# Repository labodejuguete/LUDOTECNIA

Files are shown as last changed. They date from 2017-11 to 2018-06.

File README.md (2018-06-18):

# LUDOTECNIA
LUDOTECNIA es un circuito sonoro basado en ATTINY85 y la vez el lanzamiento físico del disco del mismo nombre (j.crowe)
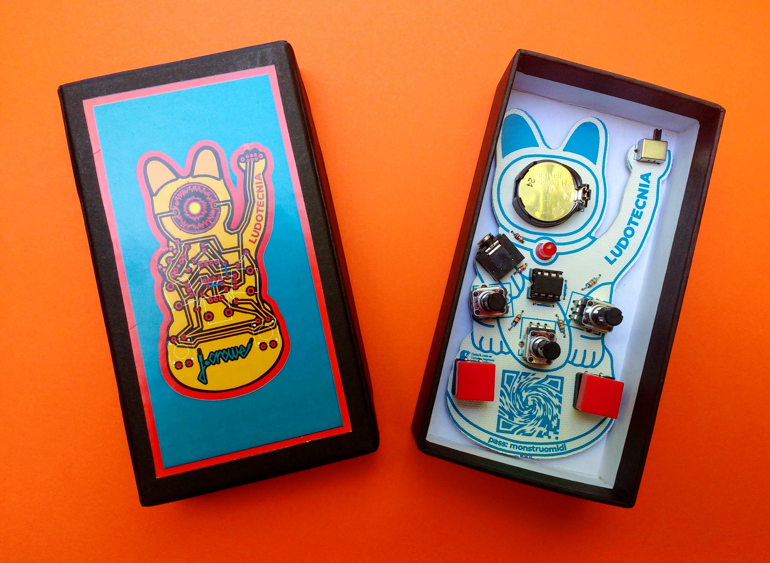
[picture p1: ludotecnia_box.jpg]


VIDEO: https://youtu.be/s6Rd__J4UZs

LUDOTECNIA hace uso del código de Kastle VCO desarrollado por Vaclav Pelousek
open source license: CC BY SA
https://github.com/bastl-instruments/kastle/tree/master/kastleSynthe_VCO
http://www.bastl-instruments.com

LUDOTECNIA fue diseñado con Fritzing e Inkscape
http://fritzing.org/home/
https://inkscape.org

PODÉS ESCUCHAR EL DISCO ONLINE EN EL SIGUIENTE ENLACE:
http://www.jcrowe.xyz/ludotecnia/

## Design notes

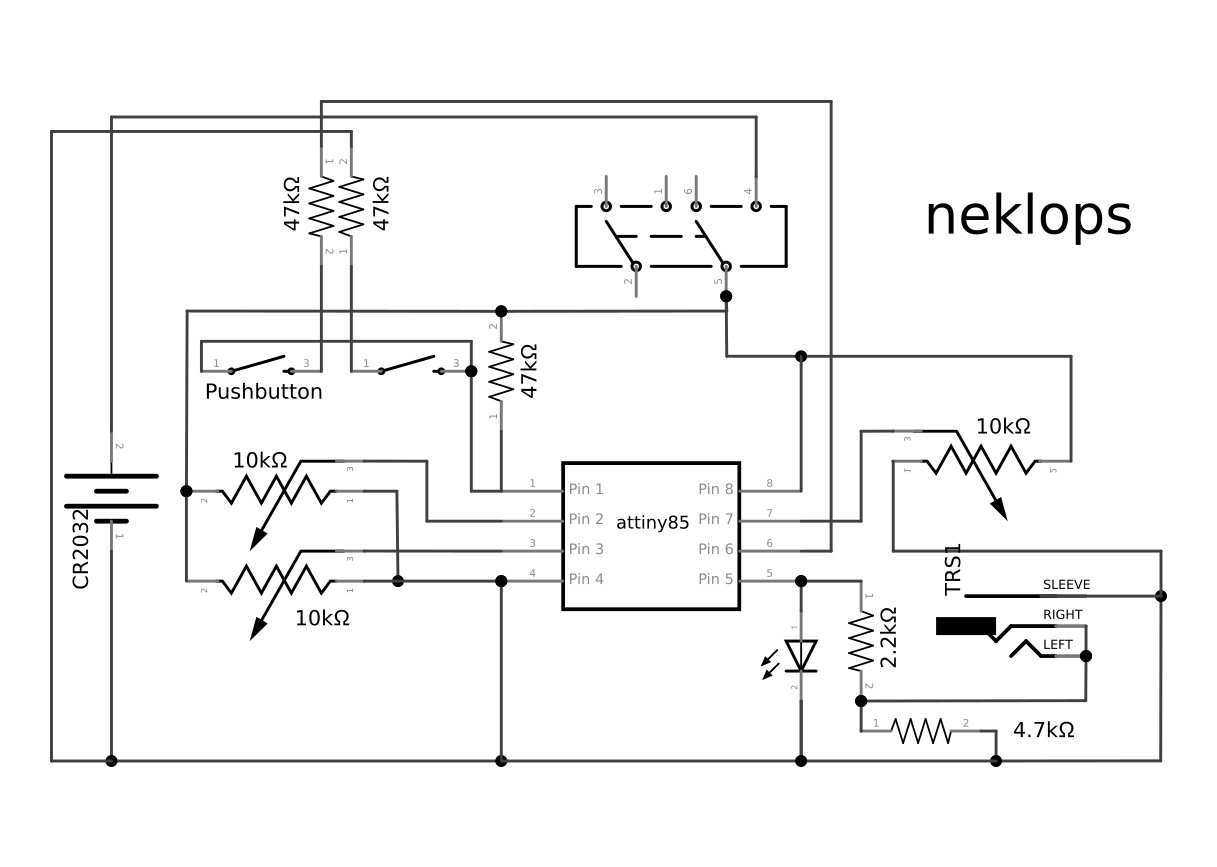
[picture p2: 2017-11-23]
hardware/neklops_schematic.jpg

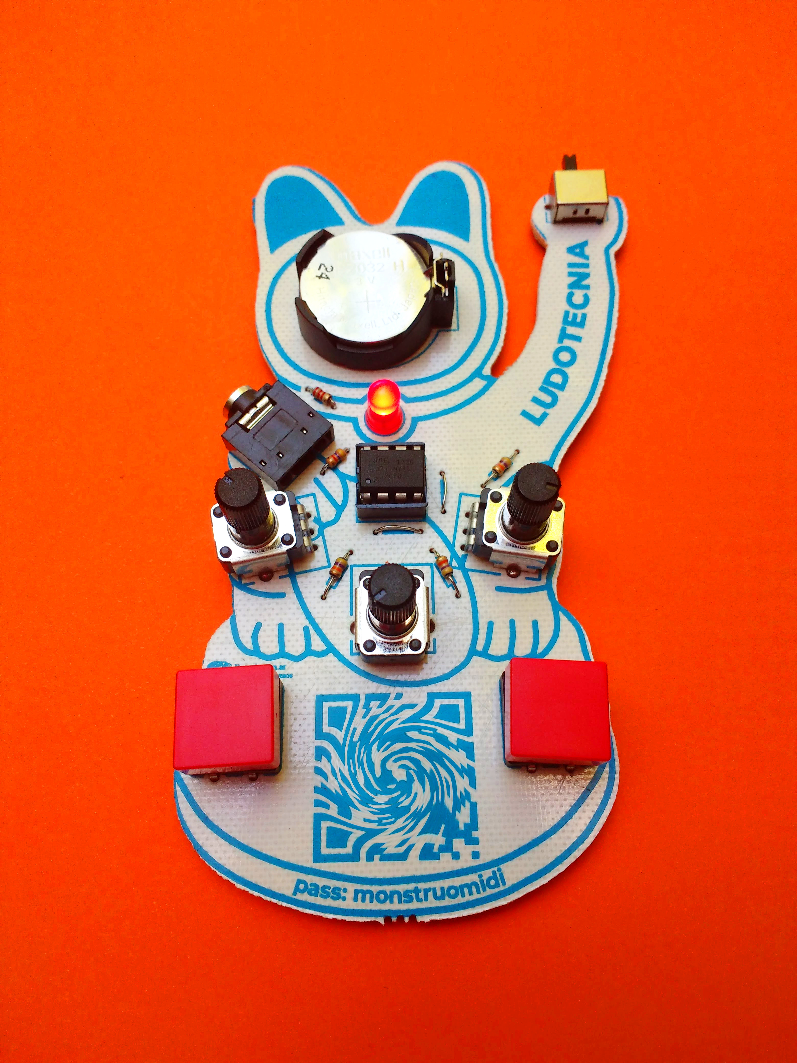
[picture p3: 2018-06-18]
ludotecnia_front.jpg

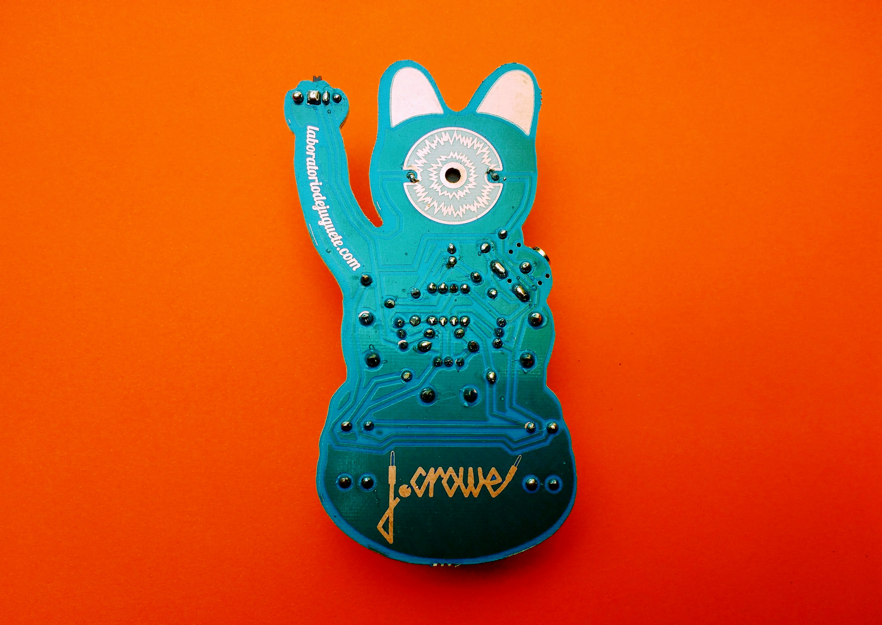
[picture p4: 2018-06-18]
ludotecnia_back.jpg

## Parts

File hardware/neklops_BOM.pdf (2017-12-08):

# Bill of Materials: neklops.fzz

## Assembly List

Label | Part Type | Properties
CR2032 | Battery Holders | package battcom_20mm_pth; variant 20pth
LED1 | Red (633nm) LED | leg yes; color Red (633nm); package 5 mm [THT]
ON/OFF | SWITCH-DPDT | package eg2211; variant eg2211

Pushbutton SWITCH-MOMENTARY-2 package tactile-pth-12mm; variant 12mm

R1 | Rotary Potentiometer (Small) | track Linear; type Rotary Shaft Potentiometer; size Rotary - 9mm; package THT; maximum resistance 10kΩ
R2 | Rotary Potentiometer (Small) | track Linear; type Rotary Shaft Potentiometer; size Rotary - 9mm; package THT; maximum resistance 10kΩ
R3 | Rotary Potentiometer (Small) | track Linear; type Rotary Shaft Potentiometer; size Rotary - 9mm; package THT; maximum resistance 10kΩ
R4 | 47kΩ Resistor | bands 4; pin spacing 400 mil; package THT; resistance 47kΩ; tolerance ±5%
R5 | 47kΩ Resistor | bands 4; pin spacing 400 mil; package THT; resistance 47kΩ; tolerance ±5%
R6 | 47kΩ Resistor | bands 4; pin spacing 400 mil; package THT; resistance 47kΩ; tolerance ±5%
R7 | 4.7kΩ Resistor | bands 4; pin spacing 400 mil; package THT; resistance 4.7kΩ; tolerance ±5%
R8 | 4.7kΩ Resistor | bands 4; pin spacing 400 mil; package THT; resistance 4.7kΩ; tolerance ±5%

Pushbutton SWITCH-MOMENTARY-2 package tactile-pth-12mm; variant 12mm

TRS1 | Audio Jack (TRS) 3.5mm | size 3.5 mm; package 4Ucon 08780 [THT]; channels Stereo (TRS)
U1 | attiny85 | version Attiny85-20PU; type Atmel AVR; package dip; variant dip08 THT

## Shopping List

Amount Part Type | Properties
1 | Battery Holders | package battcom_20mm_pth; variant 20pth
1 | Red (633nm) LED | leg yes; color Red (633nm); package 5 mm [THT]
1 | SWITCH-DPDT | package eg2211; variant eg2211
2 | SWITCH-MOMENTARY-2 package tactile-pth-12mm; variant 12mm
3 | Rotary Potentiometer (Small) | track Linear; type Rotary Shaft Potentiometer; size Rotary - 9mm; package THT; maximum resistance 10kΩ
3 | 47kΩ Resistor | bands 4; pin spacing 400 mil; package THT; resistance 47kΩ; tolerance ±5%
2 | 4.7kΩ Resistor | bands 4; pin spacing 400 mil; package THT; resistance 4.7kΩ; tolerance ±5%
1 | Audio Jack (TRS) 3.5mm | size 3.5 mm; package 4Ucon 08780 [THT]; channels Stereo (TRS)
1 | attiny85 | version Attiny85-20PU; type Atmel AVR; package dip; variant dip08 THT

Exported with Fritzing 0.9.3- http://fritzing.org

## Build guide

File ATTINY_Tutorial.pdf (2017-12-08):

LABORATORIO | DE | JUGUETE
Tutorial: | cómo | programar | el | attiny85 | en | la | IDE | de | Arduino

Antes de empezar refrescamos un poco la data acerca de la familia ATTINY25/45/85: Son los microcontroladores ideales para hacer tareas sencillas que no demanden muchos pines ni memoria.

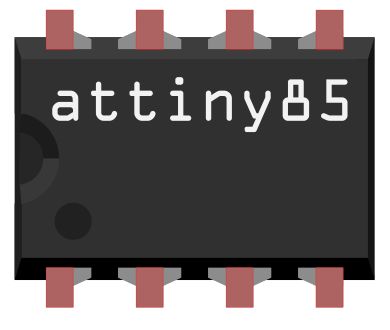
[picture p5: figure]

Ésta familia de microcontroladores tiene apenas 8 patitas y su memoria flash (el lugar donde se alberga nuestro código) es de 8, 4 o 2 kilobytes (de acuerdo al número en su nombre). Pero para muchas de las cosas que solemos hacer con arduino suele ser suficiente!

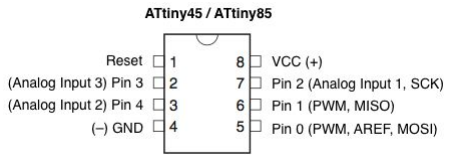
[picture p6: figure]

Como verás en el esquema de arriba, tiene 5 entradas/ salidas digitales de las cuales tres, pueden ser usadas como entradas analógicas. A que varios de tus proyectos en Arduino no usan más que ésto, no?
Y cómo hacemos para programar estas cucarachitas usando la IDE (http://www.arduino.cc/en/pmwiki.php?n=Main/Software) de Arduino?
Éstos son los pasos a seguir:
- Si no has instalado la IDE de Arduino o tienes una versión anterior a la 1.7, ingresa al siguiente link, descarga e instala la última versión disponible de acuerdo a tu sistema operativo y arquitectura:
WINDOWS (https://www.arduino.cc/download_handler.php?f=/arduino-1.8.5-windows.exe)
MAC (https://www.arduino.cc/download_handler.php?f=/arduino-1.8.5-macosx.zip)
LINUX | (32bit) (https://www.arduino.cc/download_handler.php?f=/arduino-1.8.5-linux32.tar.xz)
LINUX | (64bit) (https://www.arduino.cc/download_handler.php?f=/arduino-1.8.5-linux64.tar.xz)
- A continación te presentamos el Core (núcleo) que vamos a usar: ATTinyCore (de
| Spence Konde). (https://github.com/SpenceKonde/ATTinyCore) Puedes echar un vistazo al repositorio o por ahora simplemente copiar
| la dirección de aquí debajo:

### http://drazzy.com/package_drazzy.com_index.json

- Abrí la IDE de Arduino y dirigite a Archivo/Preferencias
- Allí encontrarás un cuadro con el nombre "Gestor de URLs adicionales de tarjetas ". Pegá en el cuadro la dirección que copiaste antes y hacé clic en OK

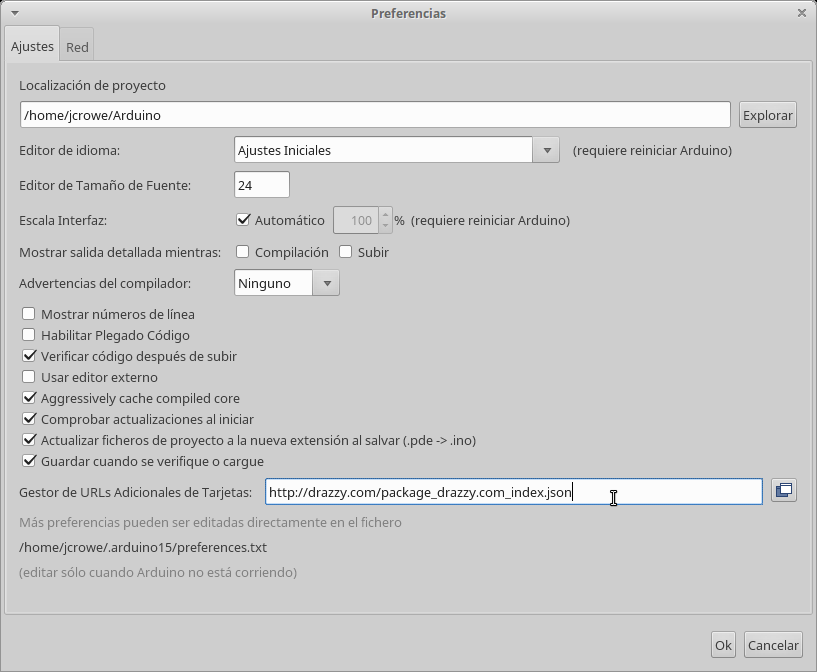
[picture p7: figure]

- Ahora dirigite a Herramientas/Placa/Gestor de tarjetas. Dale un momento al gestor para que se actualize e incorpore la ruta que pegaste en el paso anterior. Luego escribí "tiny" en el buscador. Aparecerá "ATTinyCore by Spence Konde"; hacé click en "instalar".

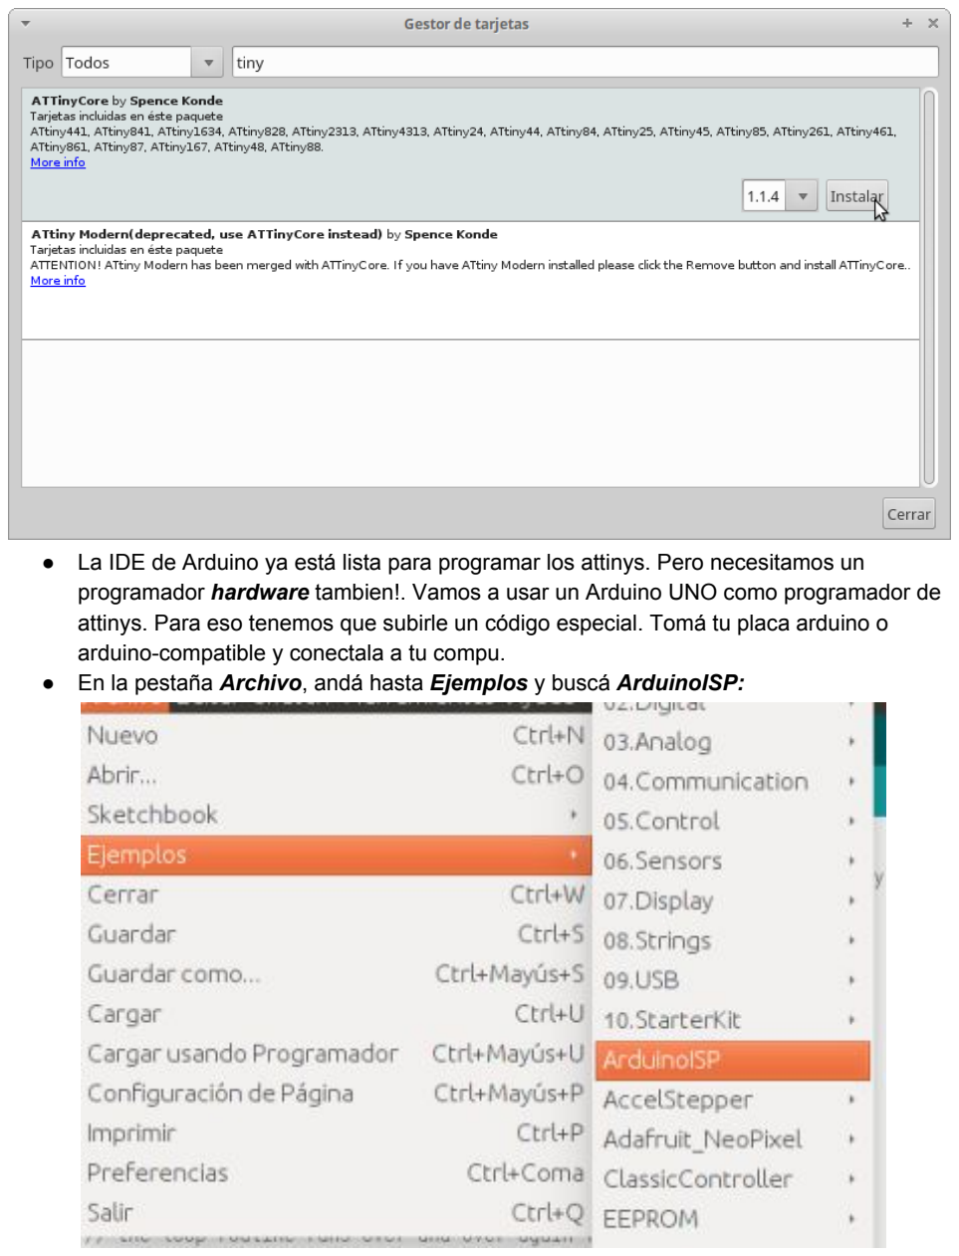
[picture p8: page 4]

- La IDE de Arduino ya está lista para programar los attinys. Pero necesitamos un programador hardware tambien!. Vamos a usar un Arduino UNO como programador de attinys. Para eso tenemos que subirle un código especial. Tomá tu placa arduino o arduino-compatible y conectala a tu compu.
- En la pestaña Archivo, andá hasta Ejemplos y buscá ArduinoISP:

- Subí el sketch a tu placa Arduino Uno (damos por sentado que ya sabés cómo elegir la placa y el puerto de comunicación):

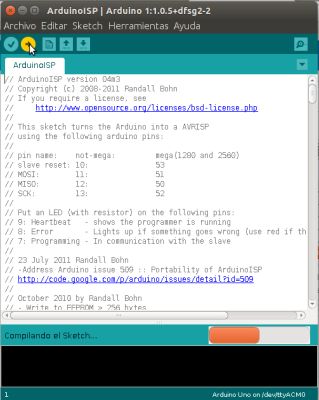
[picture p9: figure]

- Acabás de convertir a tu arduino en un programador de microcontroladores. Para usarlo como tal, sólo tenés que dar un paso más. Andá a la pestaña Herramientas, luego a Programador y elegí Arduino as ISP:

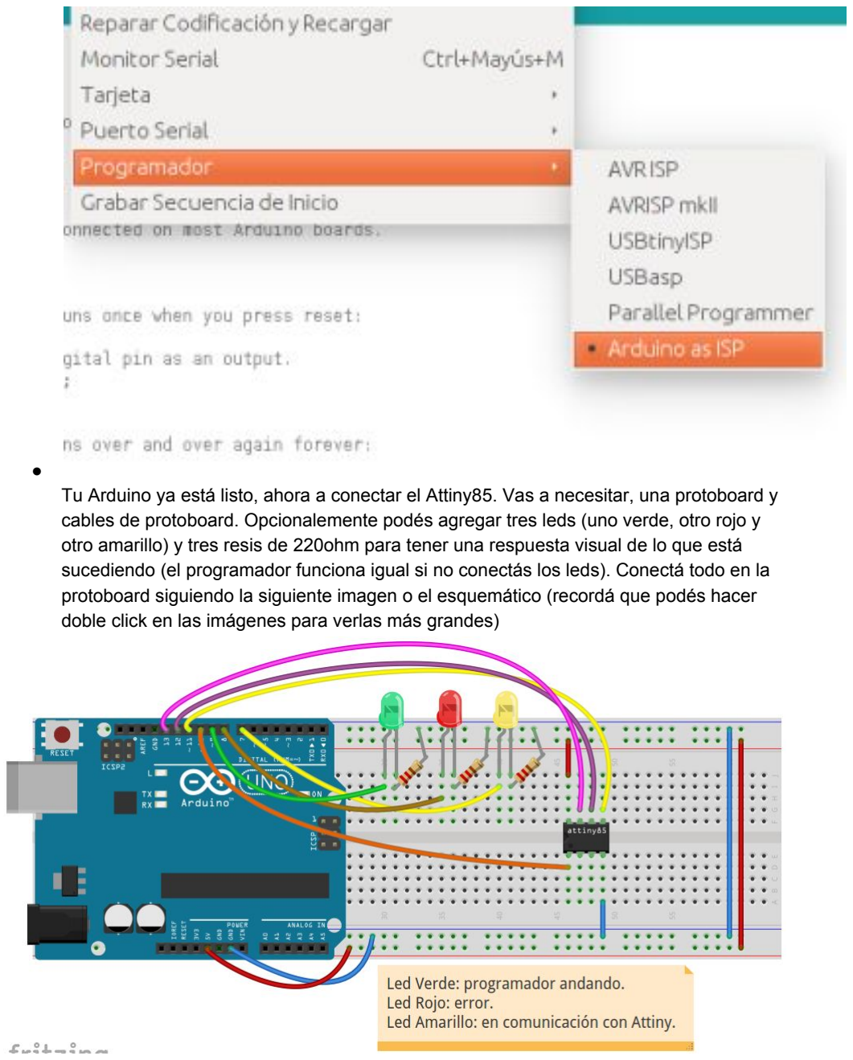
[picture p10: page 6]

●
Tu Arduino ya está listo, ahora a conectar el Attiny85. Vas a necesitar, una protoboard y cables de protoboard. Opcionalemente podés agregar tres leds (uno verde, otro rojo y otro amarillo) y tres resis de 220ohm para tener una respuesta visual de lo que está sucediendo (el programador funciona igual si no conectás los leds). Conectá todo en la protoboard siguiendo la siguiente imagen o el esquemático (recordá que podés hacer doble click en las imágenes para verlas más grandes)

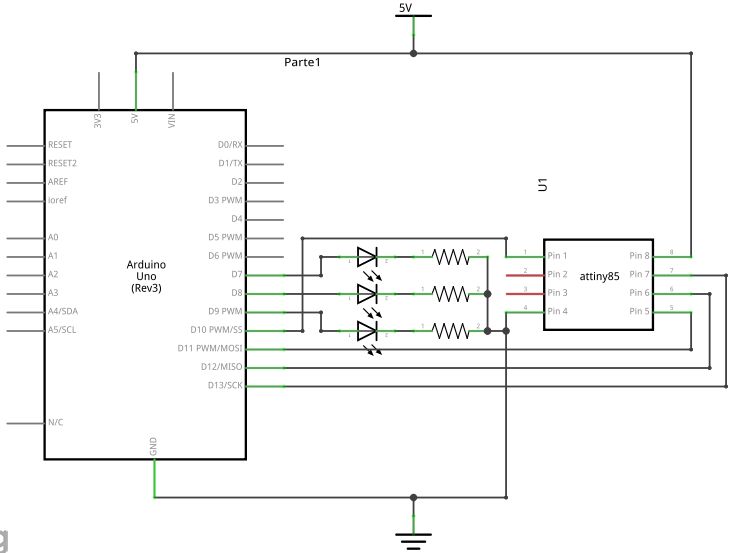
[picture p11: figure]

- Vamos a elegir el chip que estamos usando (en éste caso el attiny85). Andá a Herramientas/Placa y deslizate hacia abajo hasta que aparezca la opción attiny25/45/85. Seleccionala:

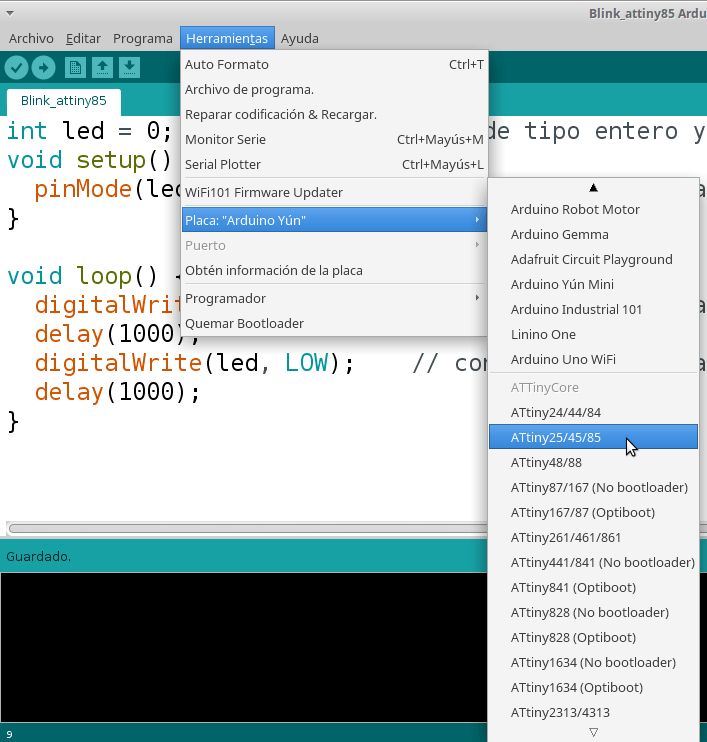
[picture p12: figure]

Si tu chip es efectivamente un Attiny85, no tenés que cambiar ninguna opción. Si en lugar de tener un attiny85, tenés un 25 o 45, vas a tener que cambiar el tipo de chip ingresando nuevamente a Herramientas.

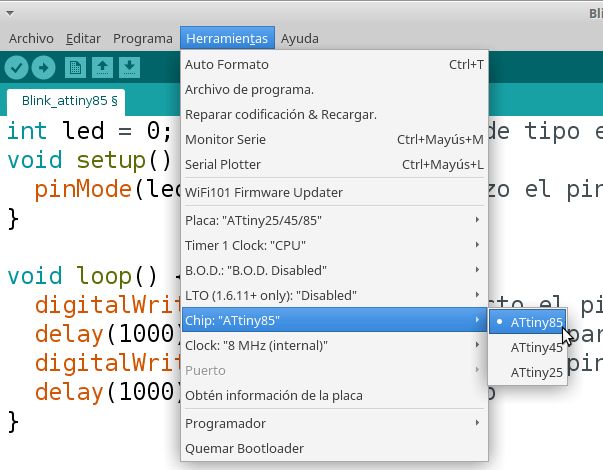
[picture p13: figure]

La siguiente acción se realiza sólo una vez, al principio, con cada chip que compres. Es la carga del bootloader o sistema de arranque. Una vez quemado el bootloader, tu chip está listo para ser programado una y otra vez. Andá a Herramientas y presioná "Cargar bootloader (recordá tener seleccionado "Arduino as ISP" como programador).

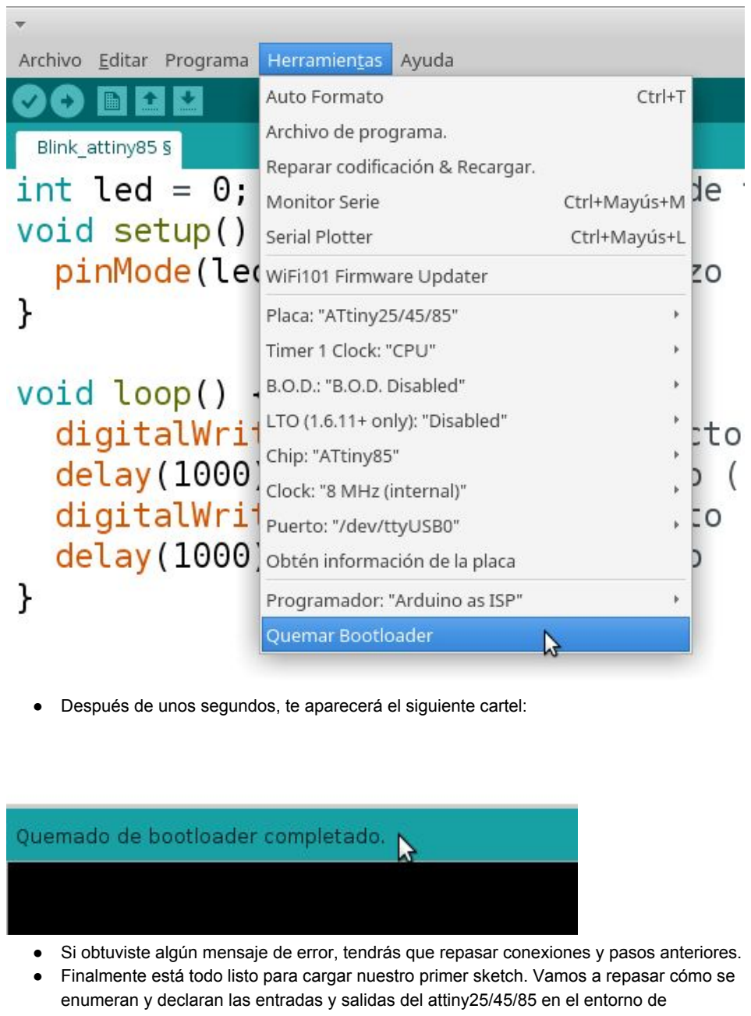
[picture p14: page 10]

- Después de unos segundos, te aparecerá el siguiente cartel:
- Si obtuviste algún mensaje de error, tendrás que repasar conexiones y pasos anteriores.
- Finalmente está todo listo para cargar nuestro primer sketch. Vamos a repasar cómo se enumeran y declaran las entradas y salidas del attiny25/45/85 en el entorno de programación de Arduino. En rojo verás el número con el que se declaran las entradas analógicas y en celeste las entradas/salidas digitales. En verde están indicadas las salidas digitales que permiten usar la función "analogWrite" (PWM).

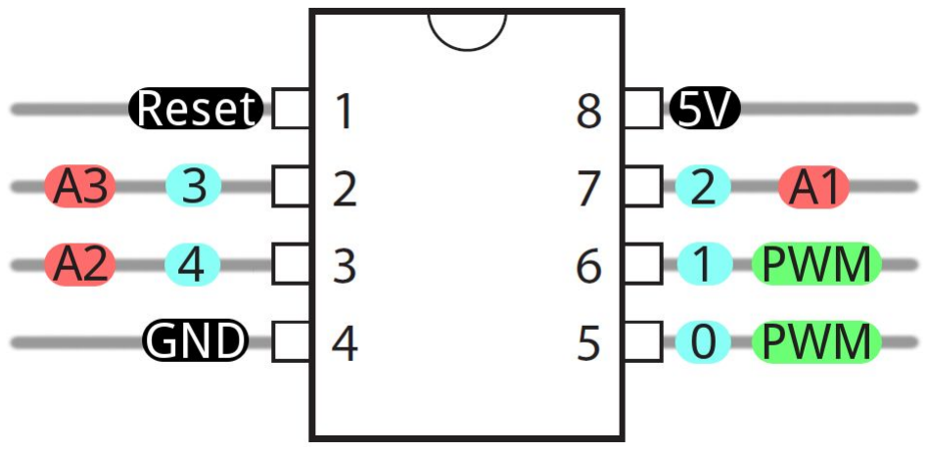
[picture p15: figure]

- Para testear la comunicación entre arduino y attiny (en este caso un attiny85) , vamos a usar el clásico ejemplo Blink que hace parpadear un led a un ritmo constante de un segundo. Para ello usaremos un led (y una resistencia de 220 Ohms) conectado a la pata 5 (Digital 0) Acá tenés un LINK (https://create.arduino.cc/editor/toylab/379f984c-477a-4e85-be1e-d4f69fa686af/preview) al archivo ya modificado para su uso en este tutorial. Copiá y pegá en un sketch vacío. Alternativamente podés abrir el ejemplo blink ubicado en Archivo/Ejemplo/Basics/Blink y reemplazar LED_BUILTIN por el valor 0 en todos los casos. Si copiaste y pegaste el texto del link, tu sketch se verá así:

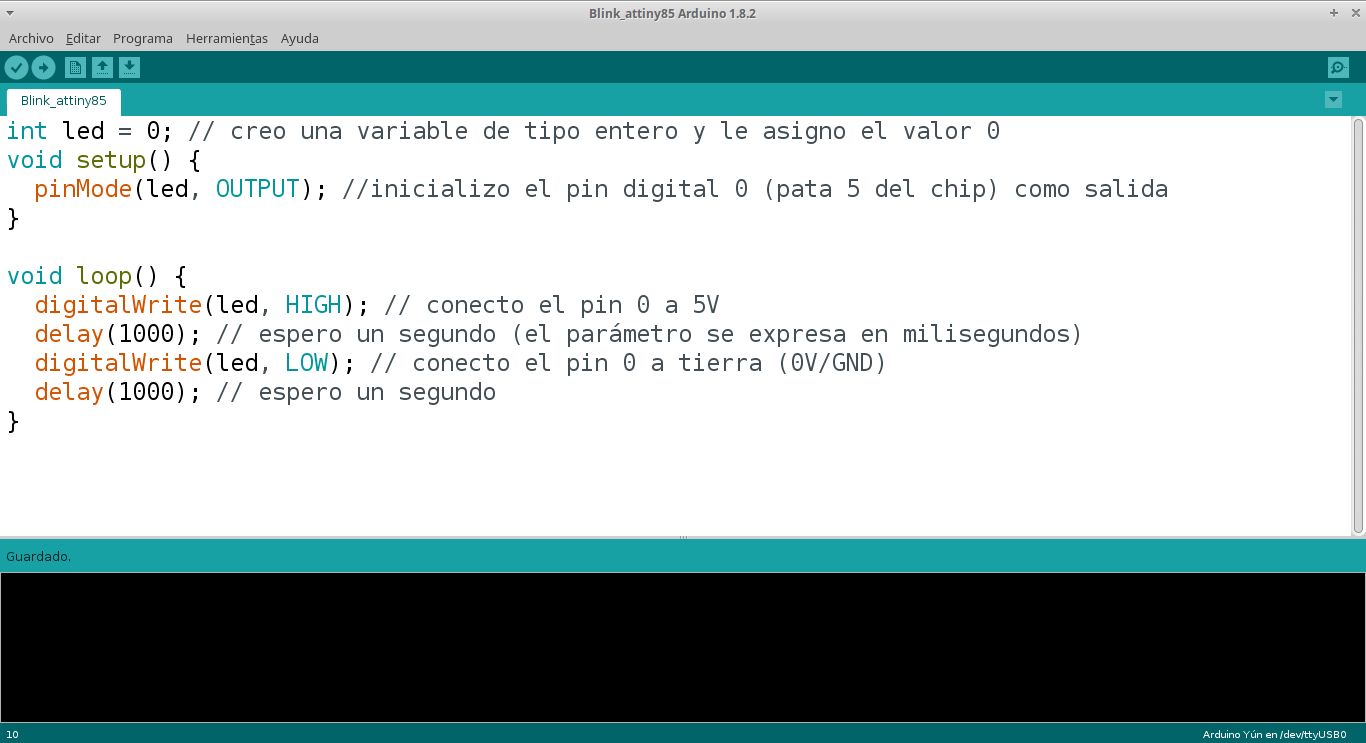
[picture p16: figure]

- Subí el código al chip apretando el botón Cargar. Si colocaste los leds indicadores, deberías ver parpadear el led amarillo, lo que indica que está cargándose el código al attiny. Cuando veas el cartel de carga terminada, tu attiny ya estará programado! Ahora es momento de desarmar tu circuito anterior o buscar otra protoboard para ensamblar el circuito con el led (recordá no usar más de 5V!!!). El attiny anda fantástico con dos pilas AA (sumando 3V en total). Si no tenés ni pilas ni regulador, podés alimentar tu circuito con 5V y GND de tu arduino conectado a USB. El circuito es el siguiente:

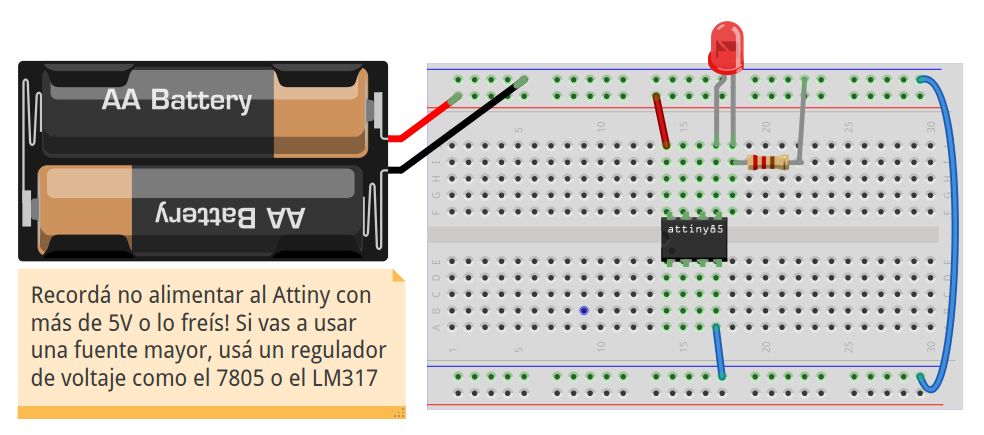
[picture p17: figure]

- A esta altura, si todo está OK, deberías ver tu led parpadeando:Misión cumplida!

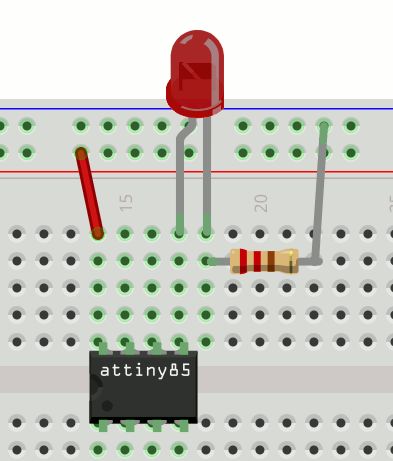
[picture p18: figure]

- Si algo falló en el camino, no te olvides de "triplechequear" instrucciones y conexiones. Ya sabés programar attinys, si querés experimentar con ejemplos más complejos, podés investigar proyectos del labo como el Gamelín MINI (http://fritzing.org/projects/gamelin-mini) o Neklops. (https://github.com/labodejuguete/NEKLOPS)

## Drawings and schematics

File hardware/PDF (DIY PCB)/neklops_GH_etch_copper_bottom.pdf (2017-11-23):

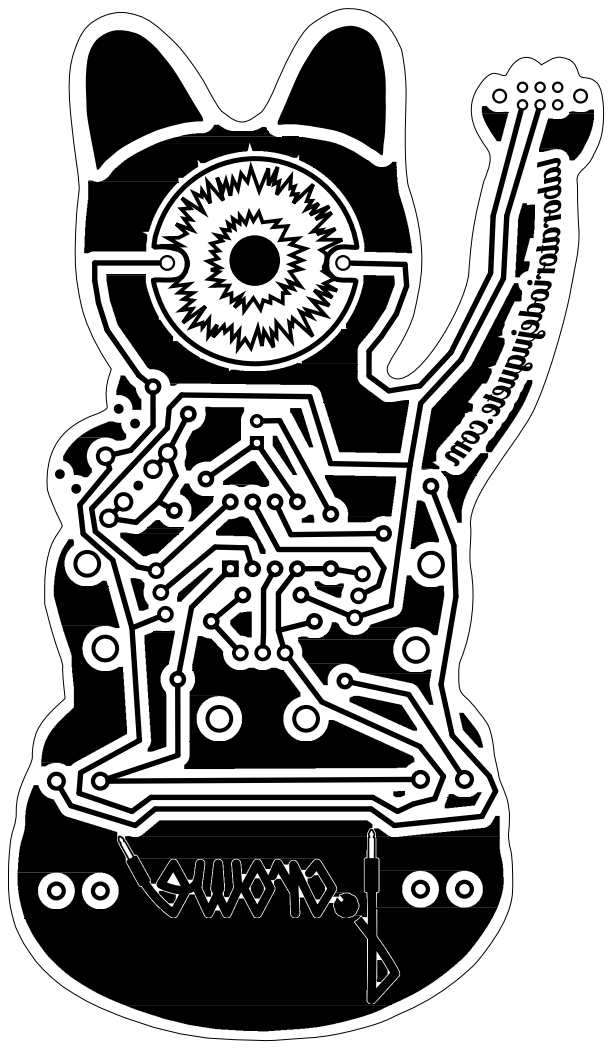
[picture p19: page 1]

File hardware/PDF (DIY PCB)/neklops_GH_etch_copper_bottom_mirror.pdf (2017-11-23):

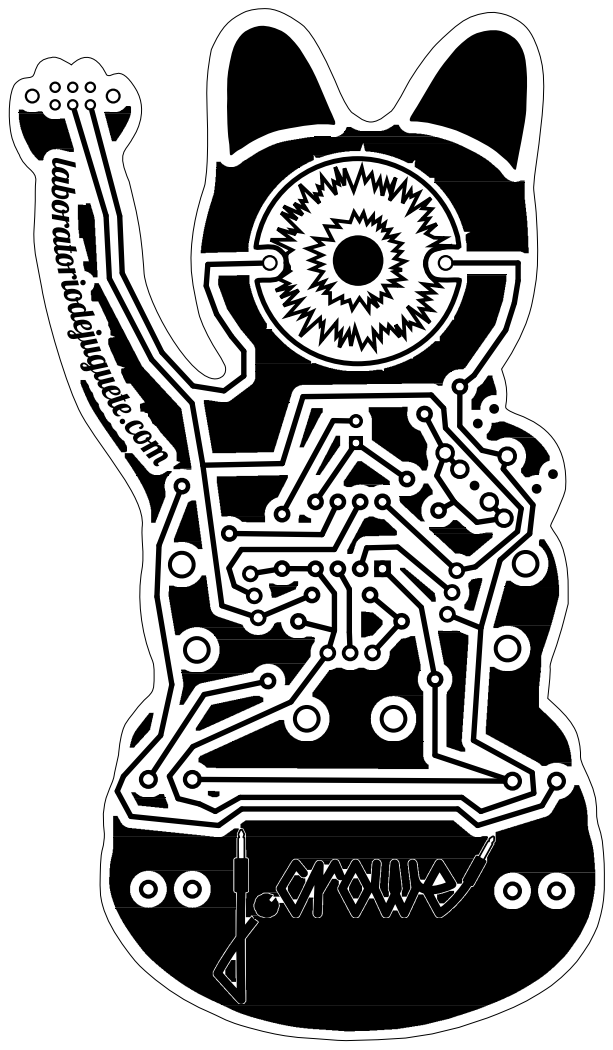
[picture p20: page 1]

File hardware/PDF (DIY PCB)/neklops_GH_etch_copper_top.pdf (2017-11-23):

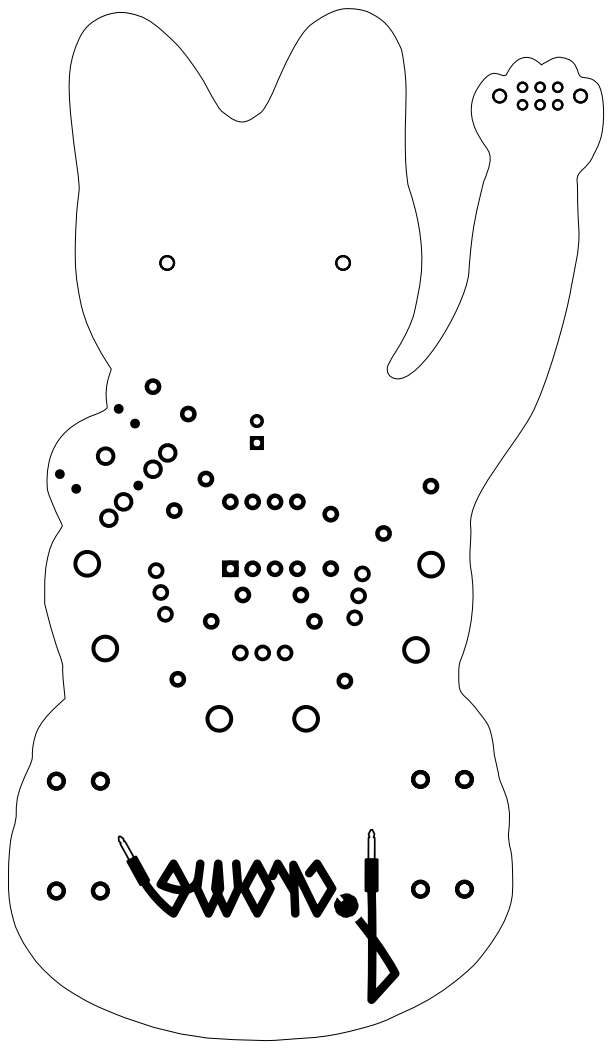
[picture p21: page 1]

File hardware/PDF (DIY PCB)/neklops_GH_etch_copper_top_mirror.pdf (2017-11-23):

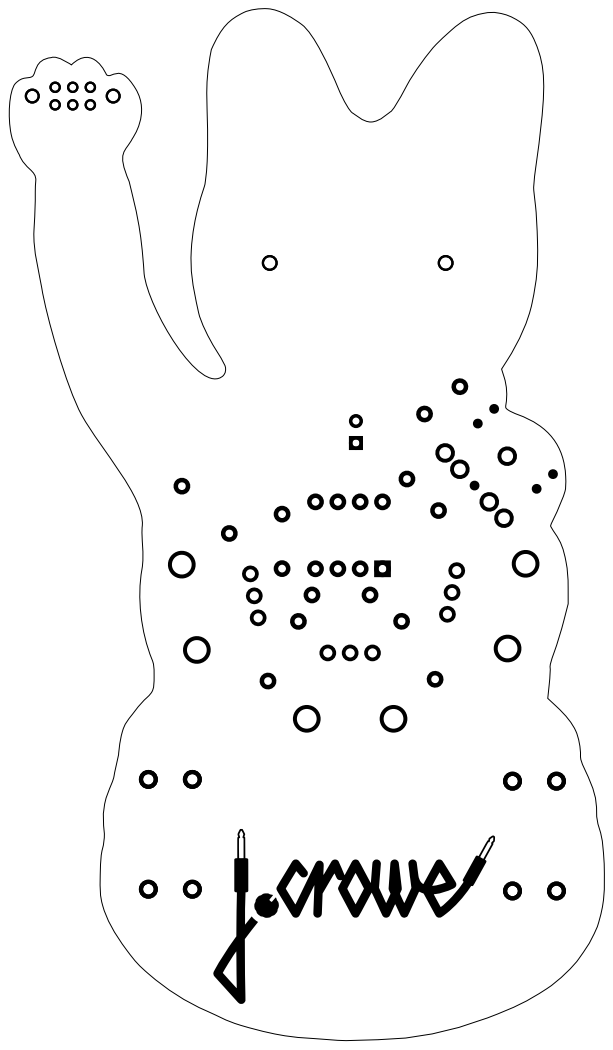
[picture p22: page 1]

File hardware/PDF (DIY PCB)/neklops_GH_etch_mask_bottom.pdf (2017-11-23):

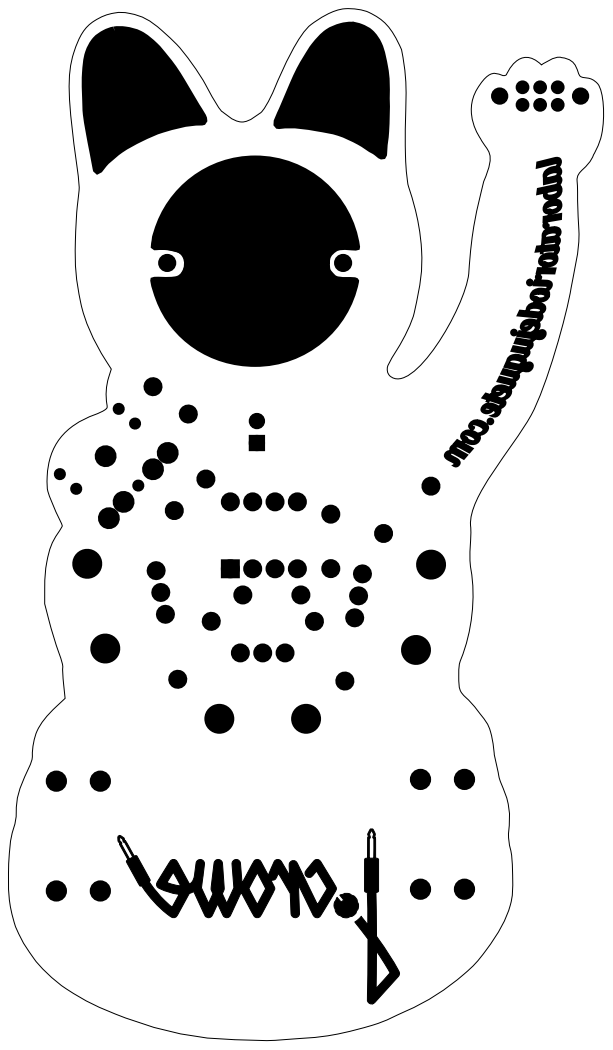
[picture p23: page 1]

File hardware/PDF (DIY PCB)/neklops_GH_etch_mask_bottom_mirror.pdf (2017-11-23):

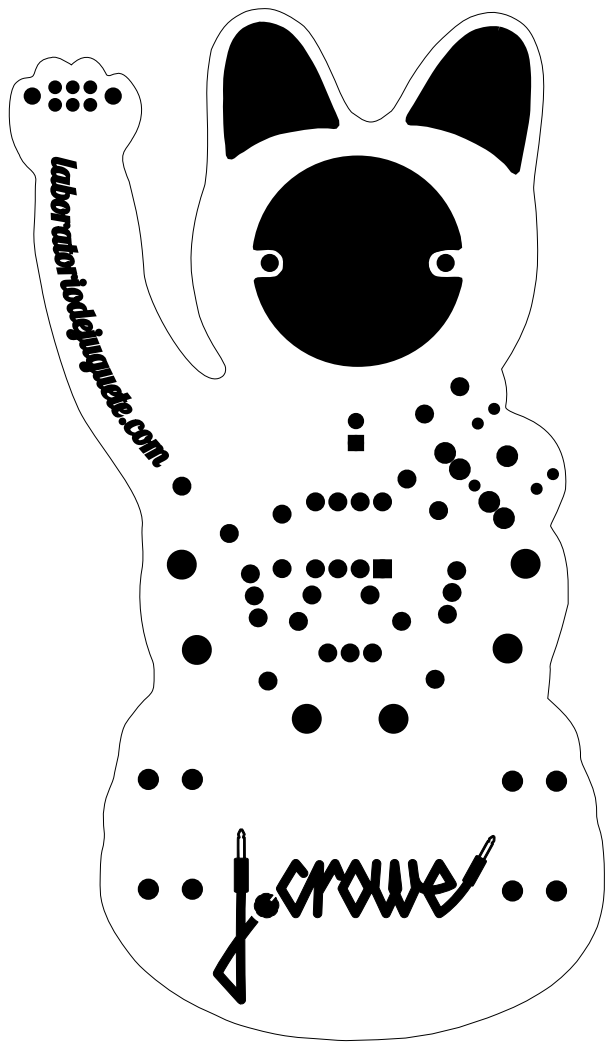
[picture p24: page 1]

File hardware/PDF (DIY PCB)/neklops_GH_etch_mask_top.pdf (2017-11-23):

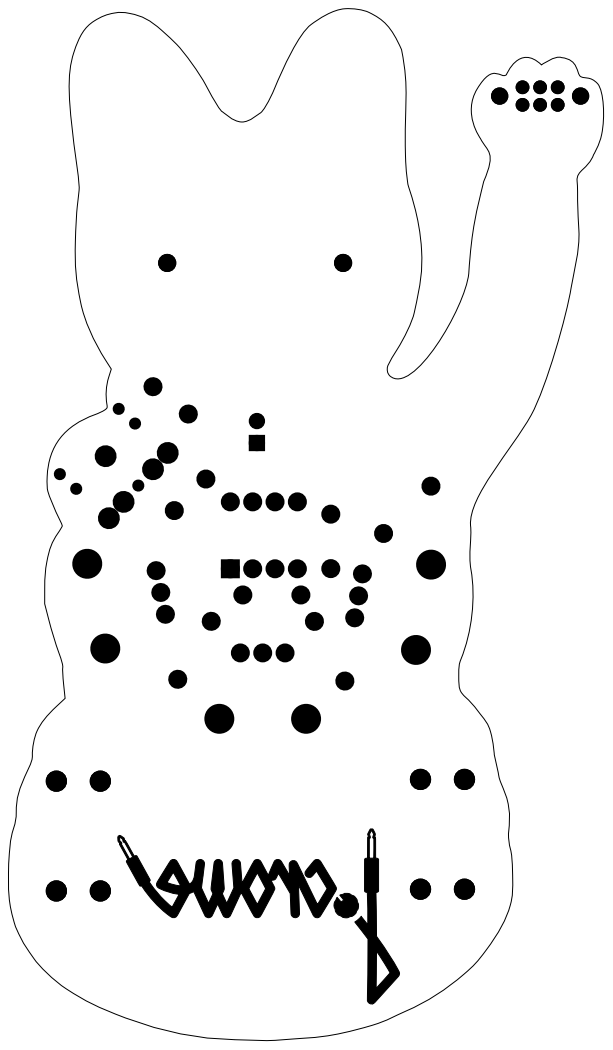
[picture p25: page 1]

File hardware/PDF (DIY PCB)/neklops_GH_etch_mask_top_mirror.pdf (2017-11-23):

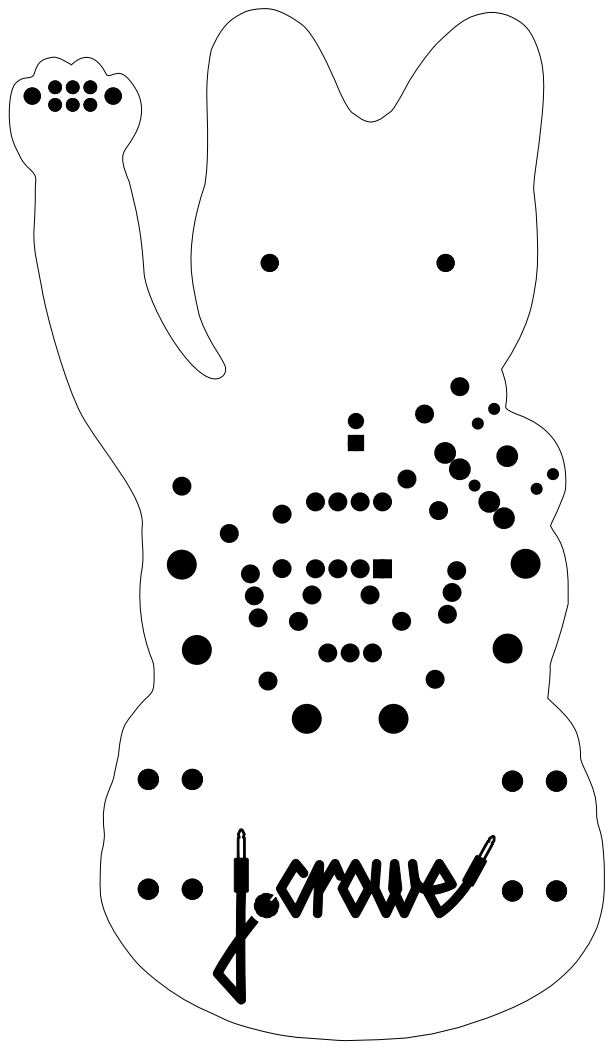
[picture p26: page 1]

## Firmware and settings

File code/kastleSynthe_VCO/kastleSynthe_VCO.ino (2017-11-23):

/*
KASTLE VCO v 1.0


Features
-3 synthesis modes = phase modulation, phase distortion, tarck & hold modulation
-regular waveform output by PWM
-square wave output
-3 sound parameters controlled by voltage inputs
-voltage selectable synthesis modes on weak I/O Reset pin


ideas 
 -transfer wavetable to ram and see if it is faster
 -update parameters at the beginning of waveoform cycle to see if it improoves stability
 -dynamicly lower the resolution of the VCO
 
Writen by Vaclav Pelousek 2016
open source license: CC BY SA
http://www.bastl-instruments.com
 
 
-software written in Arduino 1.0.6 - used to flash ATTINY 85 running at 8mHz
-created with help of the heavenly powers of internet and several tutorials that you can google out
-i hope somebody finds this code usefull

thanks to 
-Lennart Schierling for making some work on the register access
-Uwe Schuller for explaining the capacitance of zener diodes
-Peter Edwards for making the inspireing bitRanger
-Ondrej Merta for being the best boss
-and the whole bastl crew that made this project possible

 */
 
#define F_CPU 8000000  // This is used by delay.h library
#include <stdlib.h>
#include <avr/interrupt.h>
#include <avr/io.h>        // Adds useful constants
#include <util/delay.h>

#include "SINE.h" //sinewave wavetable - modified but originnaly from the Mozzi library
//#include <SAW.h>
//#include <CHEB4.h>


//for debugging purposes
#include "SoftwareSerial.h" 
const int Rx = 8; 
const int Tx = 3; 
//SoftwareSerial mySerial(Rx, Tx); //use only for debugging

//global variables
#define WSMAP_POINTS 5
uint16_t wsMap[10]={
  0,63,127,191,234,   15,100,160,210,254};


uint8_t _out;
uint16_t time;
uint8_t mode;
uint8_t analogChannelRead=1;
uint8_t analogValues[4];
uint8_t lastAnalogValues[4];
uint8_t out;
uint8_t pwmCounter;
uint8_t mapLookup[256];
uint8_t _clocks;
bool flop;
uint8_t incr=6,_incr=6;
uint8_t lastOut;
uint8_t bitShift=3;
uint16_t osc2offset=255;
uint8_t lastAnalogChannelRead;
bool firstRead=false;

uint8_t pwmIncrement,_upIncrement,_downIncrement,upIncrement,downIncrement;
bool quantizer;
const uint8_t analogToDigitalPinMapping[4]={ 
  6,PORTB2,PORTB4,PORTB3};
  
  
//defines for synth types
//all are dual oscillator setups - 
#define PHASE_DIST 0 // phase distortion -
#define FM 1 //aka phase modulation
#define TAH 2 //aka track & hold modulation (downsampling with T&H)


#define LOW_THRES 150
#define HIGH_THRES 162
#define LOW_MIX 300
#define HIGH_MIX 900

//defines for synth parameters
#define PITCH 2
#define WS_1 3
#define WS_2 1


uint32_t curveMap(uint8_t value, uint8_t numberOfPoints, uint16_t * tableMap){
  uint32_t inMin=0, inMax=255, outMin=0, outMax=255;
  for(int i=0;i<numberOfPoints-1;i++){
    if(value >= tableMap[i] && value <= tableMap[i+1]) {
      inMax=tableMap[i+1];
      inMin=tableMap[i];
      outMax=tableMap[numberOfPoints+i+1];
      outMin=tableMap[numberOfPoints+i];
      i=numberOfPoints+10;
    }
  }
  return map(value,inMin,inMax,outMin,outMax);
}


void createLookup(){
  for(uint16_t i=0;i<256;i++){
    mapLookup[i]=curveMap(i,WSMAP_POINTS,wsMap);
  }
}



void setup()  { //happends at the startup
  digitalWrite(5,HIGH); //turn on pull up resistor for the reset pin
  createLookup(); //mapping of knob values is done thru a lookuptable which is generated at startup from defined values
  //set outputs
  pinMode(0, OUTPUT);
  pinMode(1, OUTPUT);
  //serial for debugging only
  //mySerial.begin(9600);
  
  setTimers(); //setup interrupts

  //setup ADC and run it in interrupt
  init();
  connectChannel(analogChannelRead);
  startConversion();


} 

void setTimers(void)
{
  /*
  TCCR0A=0;
   TCCR0B=0;
   bitWrite(TCCR0A,COM0A0,0);
   bitWrite(TCCR0A,COM0A1,1);
   bitWrite(TCCR0A,COM0B0,0);
   bitWrite(TCCR0A,COM0B1,1);
   bitWrite(TCCR0A,WGM00,1);
   bitWrite(TCCR0A,WGM01,1);
   bitWrite(TCCR0B,WGM02,0);
   bitWrite(TCCR0B,CS00,1);
   */
  TCCR0A = 2<<COM0A0 | 2<<COM0B0 | 3<<WGM00;
  TCCR0B = 0<<WGM02 | 1<<CS00;

  //  setup timer 0 to run fast for audiorate interrupt 
  TCCR1 = 0;                  //stop the timer
  TCNT1 = 0;                  //zero the timer
  GTCCR = _BV(PSR1);          //reset the prescaler
  OCR1A = 250;                //set the compare value
  // OCR1C = 31;
  TIMSK = _BV(OCIE1A);// | _BV(TOIE0);    //TOIE0    //interrupt on Compare Match A
  //start timer, ctc mode, prescaler clk/1    
  TCCR1 = _BV(CTC1) | _BV(CS12) ;//| _BV(CS11);//  | _BV(CS11) ;// //| _BV(CS13) | _BV(CS12) | _BV(CS11) |
  sei();
  TIMSK |=_BV(TOIE0);   
}

uint16_t clocks(){
  //return _clocks;
  return TCNT0|(_clocks<<8);
}

ISR(TIMER0_OVF_vect){ // increment _clocks at PWM interrupt overflow - this gives 16bit time consciousnes to the chip (aproxx 2 seconds before overflow)
  _clocks++; 
}


ISR(TIMER1_COMPA_vect)  // render primary oscillator in the interupt
{
 
  out+=incr; // increment the oscillator saw core
  if((analogValues[WS_2])<pwmCounter) OCR0B=255; //render pulse oscillator output
  else OCR0B=0;
  
  pwmCounter=out<<1; // speed up the frequency of the square wave output twice
  TCNT1 = 0; //reset interupt couter
}



void loop() { 

  if(mode==PHASE_DIST){

    if(out<incr){ //sync oscillators
      _out=0;
    }
    uint8_t waveShape=(analogValues[WS_2])<<1;
    if(analogValues[WS_2]>170) {
      if(out!=lastOut) OCR0A =   (((256-out)|waveShape) * (((char)pgm_read_byte_near(SIN256_DATA+_out))+128))>>8;  
    }
    else{
      OCR0A =   (((256-out)|waveShape) * (((char)pgm_read_byte_near(SIN256_DATA+_out))+128))>>8;
    }
    lastOut=out;
  }

  if(mode==FM){
    uint8_t _mod= ((((analogValues[WS_2])+1)*((char)pgm_read_byte_near(SIN256_DATA+_out)+128))>>6) +out;
    OCR0A=  (char)pgm_read_byte_near(SIN256_DATA+_mod)+128;
  }

  if(mode==TAH){
    if(out>(analogValues[WS_2]-15)){
      OCR0A=  (char)pgm_read_byte_near(SIN256_DATA+_out)+128;
    }
  }

  if(clocks()-time>((osc2offset-analogValues[WS_1])<<bitShift)){ // render secondary oscillator in the loop
   time=clocks(); 
    _out+=_incr; // increment the oscillator saw core
  }
  else{
    if(analogValues[0]<LOW_THRES)  mode=PHASE_DIST, incr=11,_incr=6, bitShift=2, osc2offset=270; 
    else if(analogValues[0]>HIGH_THRES) mode=TAH, incr=24,_incr=6,bitShift=4,osc2offset=255;
    else mode = FM, incr=11,_incr=5,bitShift=4,osc2offset=255;
  }
  //_delay_us(250);
}




ISR(ADC_vect){ // interupt triggered ad completion of ADC counter
  if(!firstRead){ // discard first reading due to ADC multiplexer crosstalk
  //update values and remember last values
    lastAnalogValues[analogChannelRead]=analogValues[analogChannelRead];
    analogValues[analogChannelRead]= getConversionResult()>>2;
  //set ADC MULTIPLEXER to read the next channel
    lastAnalogChannelRead=analogChannelRead;
    analogChannelRead++;
    if(analogChannelRead>3) analogChannelRead=0;
    connectChannel(analogChannelRead);
  // set controll values if relevant (value changed)
    if(lastAnalogChannelRead==PITCH && lastAnalogValues[PITCH]!=analogValues[PITCH]) setFrequency(constrain(mapLookup[analogValues[PITCH]]<<2,0,1015));
    if(lastAnalogChannelRead==WS_1 && lastAnalogValues[WS_1]!=analogValues[WS_1]) analogValues[WS_1]= mapLookup[analogValues[WS_1]];
    if(lastAnalogChannelRead==WS_2 && lastAnalogValues[WS_2]!=analogValues[WS_2]) analogValues[WS_2]= mapLookup[analogValues[WS_2]];
    firstRead=true;
  //start the ADC - at completion the interupt will be called again
    startConversion();

  }
  else{ 
    /* 
    at the first reading off the ADX (which will not used) 
    something else will happen the input pin will briefly turn to output to 
    discarge charge built up in passive mixing ciruit using zener diodes
    because zeners have some higher unpredictable capacitance, various voltages might get stuck on the pin
    */
    if( mode==PHASE_DIST && analogChannelRead!=PITCH){ //this would somehow make the  reset pin trigger because the reset pin is already pulled to ground
    }
    else{ 
      if(analogValues[analogChannelRead]<200) bitWrite(DDRB,analogToDigitalPinMapping[analogChannelRead],1);
      bitWrite(DDRB,analogToDigitalPinMapping[analogChannelRead],0);
      bitWrite(PORTB,analogToDigitalPinMapping[analogChannelRead],0);
    } 
    firstRead=false;
    startConversion();
  }
}


void setFrequency(int _freq){ //set frequency of the interupt for primary oscillator
  _freq=1024-_freq;
  uint8_t preScaler=_freq>>7;
  preScaler+=2; //*2
  pwmIncrement=4;
  _upIncrement=pwmIncrement*upIncrement;
  _downIncrement=pwmIncrement*downIncrement;
  for(uint8_t i=0;i<4;i++) bitWrite(TCCR1,CS10+i,bitRead(preScaler,i)); 
  uint8_t compare=_freq;
  bitWrite(compare,7,0);
  if(quantizer){ // if quantizer was implemented
    //compare=tuneTable[map(compare,0,127,0,6)];
  }
  OCR1A=compare+128; 
}



// #### FUNCTIONS TO ACCES ADC REGISTERS
void init() {
  
  ADMUX  = 0;
  bitWrite(ADCSRA,ADEN,1); //adc enabled
  bitWrite(ADCSRA,ADPS2,1); // set prescaler
  bitWrite(ADCSRA,ADPS1,1); // set prescaler
  bitWrite(ADCSRA,ADPS0,1); // set prescaler
  bitWrite(ADCSRA,ADIE,1); //enable conversion finished interupt
  bitWrite(SREG,7,1);
  // prescaler = highest division
}


// channel 8 can be used to measure the temperature of the chip
void connectChannel(uint8_t number) {
  ADMUX &= (11110000);
  ADMUX |= number;
}

void startConversion() {
  bitWrite(ADCSRA,ADSC,1); //start conversion
}

bool isConversionFinished() {
  return (ADCSRA & (1<<ADIF));
}

bool isConversionRunning() {
  return !(ADCSRA & (1<<ADIF));
}

uint16_t getConversionResult() {
  uint16_t result = ADCL;
  return result | (ADCH<<8);
}
